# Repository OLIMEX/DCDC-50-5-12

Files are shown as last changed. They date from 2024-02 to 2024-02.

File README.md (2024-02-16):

# DCDC-50-5-12
Industrial grade -40+85C power supply module for OLinuXino. Suitrable also for 12 and 24V car battery systems.

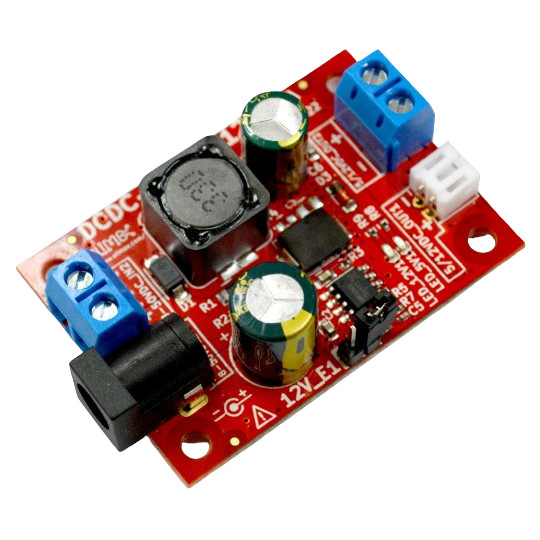
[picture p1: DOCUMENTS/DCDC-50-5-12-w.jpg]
DCDC-50-5-12-w


## Features

* Input voltage 8-50VDC
* Output voltage 5V/1.5A or 12V/1.5A
* Dimensions: 50x35x15mm

## Licenses

* Hardware is released under CERN Open Hardware Licence Version 2 - Strongly Reciprocal, all silkscreen credits to Olimex should remain;
* Software is released under GPL3 Licensee
* Documentation is released under CC BY-SA 4.0

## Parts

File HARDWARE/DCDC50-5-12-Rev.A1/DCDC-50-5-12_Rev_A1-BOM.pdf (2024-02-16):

# DCDC-50-5-12_Rev_A1-BOM 06/15/2022

Quantity | Designation | Package | Designator
2 | 1206 0.03 OHM 1% | R_1206 | R1,R2
1 | 0402 4.7 OHM 5% | R_0402 | R3
1 | 0402 1 K 5% | R_0402 | R9
1 | 0402 6.49 K 1% | R_0402 | R6
2 | 0402 10 K 1% | R_0402 | R5,R8
1 | 0402 56.2 K 1% | R_0402 | R7
1 | 33 uH 5.5A 60m 20% YSRH129-330M | HSMRH129_ 12.0x12.5x9.5(max) | L1
1 | 0402 12 PF 50V 5% C0G | C_0402 | C5
3 | 0603 100 NF 100V 10% X7R | C_0603 | C2,C4,C7
1 | 100 uF 63V 20% 10x13MM Low ESR RM5 | CPOL-RM5mm_ 10.0x16.0mm_PTH | C1
1 | 470 uF 16 V LOW ESR 20 % 8*12MM | CPOL-RM3.5mm_ 8.0x11.5mm_PTH | C6
1 | BZV55C6V2 | SOD80C-4148-KA | D3
1 | SMAJ58A | SMA | D1
1 | SS510 100V 5A 0.85V SMC | DO214AB(SMC) | D2
1 | LED 0603 RED 300 mCd | LED_0603 | LED_12V1
1 | LED 0603 GREEN 300 mCd | LED_0603 | LED_5V1
1 | TX4138(ESOIC-8) | ESOIC-8 | U1
1 | DW02R | DW02R | 5/12VDC_OUT1
2 | TB2-5MM | TB2-5mm | 8-50VDC_IN2, 5/12VDC_OUT2
1 | YDJ-1134 PWRJ-2mm (DCJ-R-20-LF) | PWRJ-2mm(YDJ-1134) | 8-50VDC_IN1
1 | HN1x2(Opened) | HN1x2_Jumper | 12V_E1
1 | NA(0603 22 OHM 5%) | R_0603_5MIL_DWS | R4
1 | NA(0805 220 PF C0G 100VDC) | C_0805_5MIL_DWS | C3

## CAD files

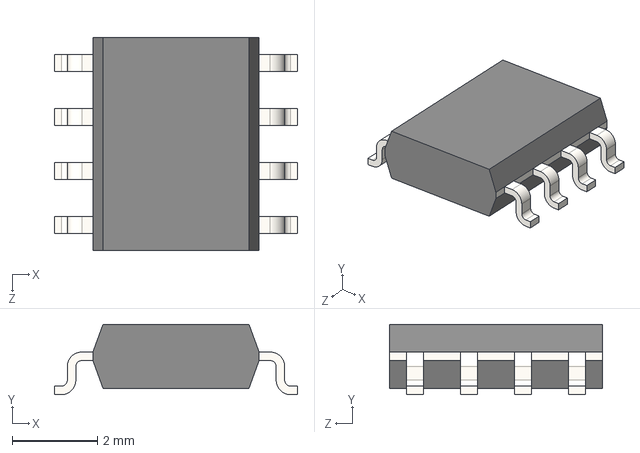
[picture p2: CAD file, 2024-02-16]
HARDWARE/DCDC50-5-12-Rev.A1/3d/SL08.step
5.70 x 1.65 x 5.00 mm

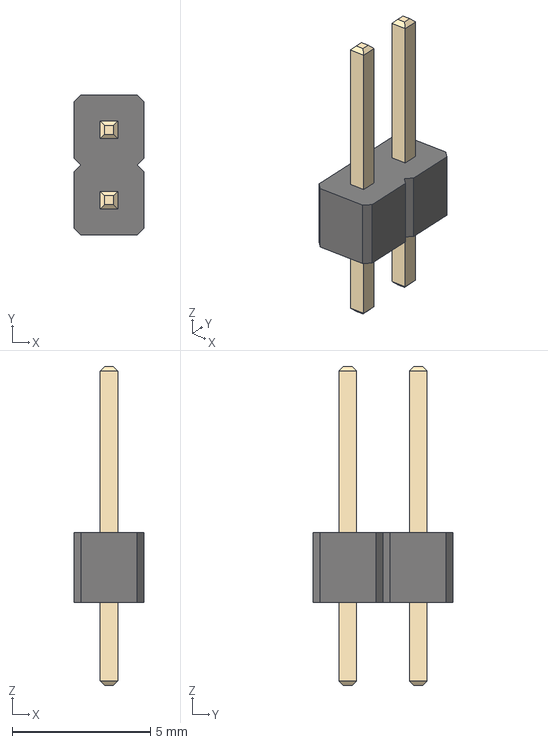
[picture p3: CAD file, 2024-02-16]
HARDWARE/DCDC50-5-12-Rev.A1/3d/HN1x2-PinHeader_1x02_P2.54mm_Vertical.step
2.54 x 5.08 x 11.5 mm

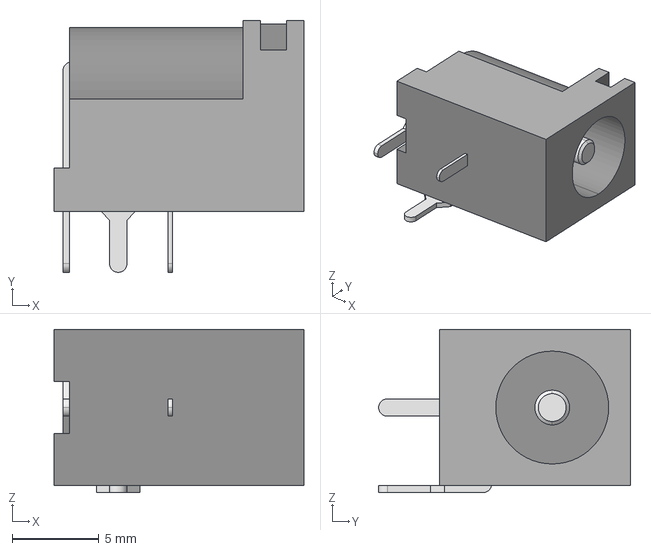
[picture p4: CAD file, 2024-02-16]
HARDWARE/DCDC50-5-12-Rev.A1/3d/pj-102ah.stp
14.4 x 14.5 x 9.40 mm

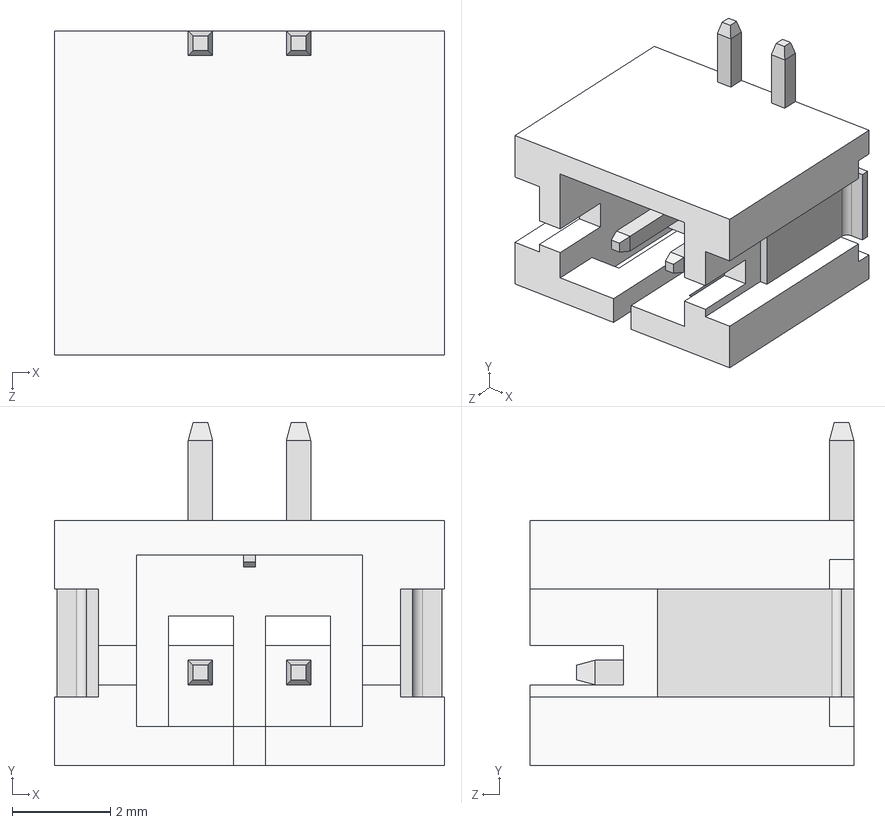
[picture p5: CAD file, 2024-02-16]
HARDWARE/DCDC50-5-12-Rev.A1/3d/JST_B2B-PH-SM4-TB(DW02R).step
7.95 x 7.00 x 6.60 mm

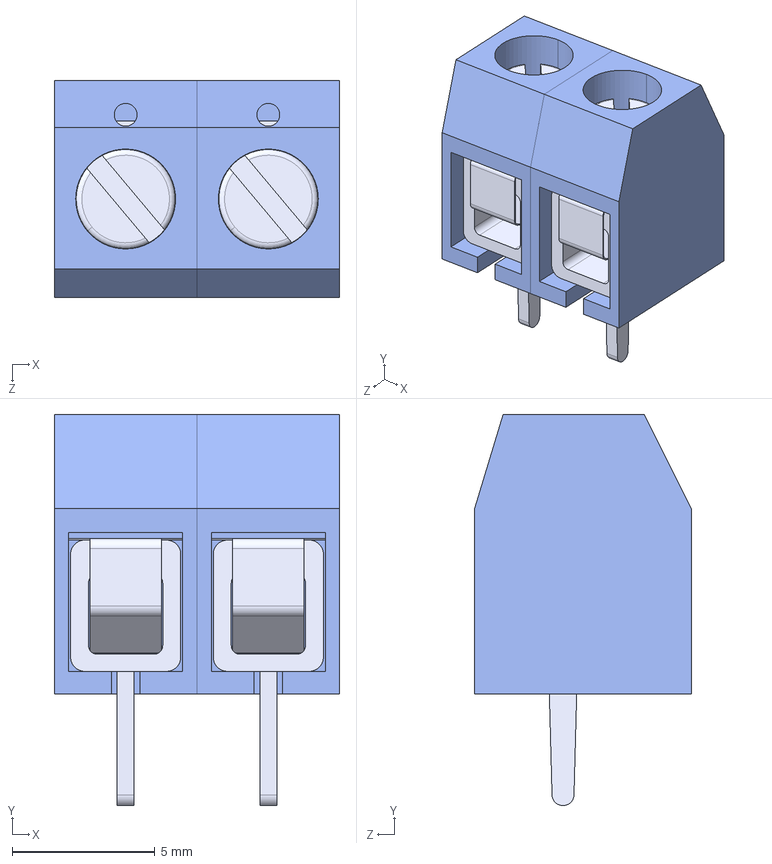
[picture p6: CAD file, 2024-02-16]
HARDWARE/DCDC50-5-12-Rev.A1/3d/TB2-5MM(DG306-5.0-2P).STEP
10.00 x 13.7 x 7.60 mm
Case___ _________ x 2
Leg___ _________ x 2
Spring___ _________ x 2
Cap___ _________ x 2

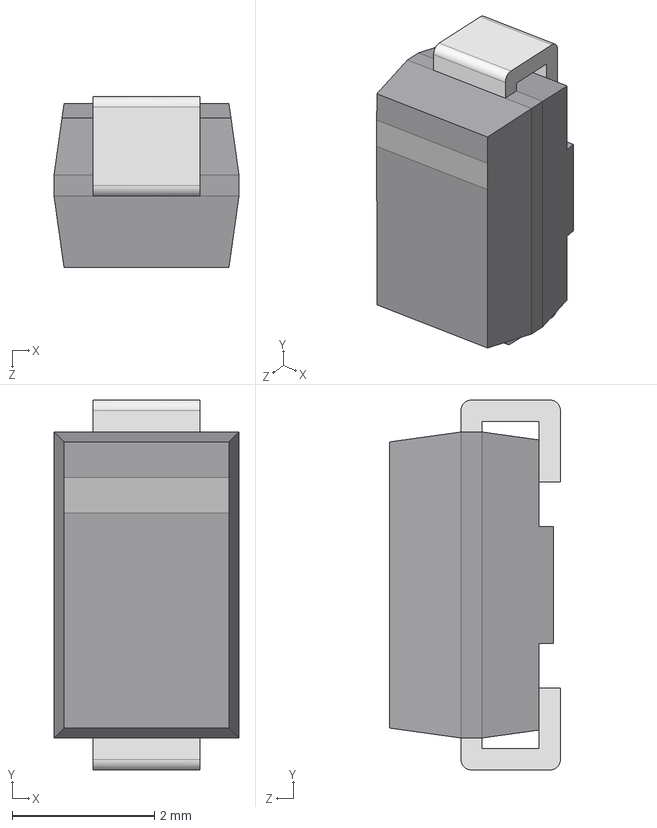
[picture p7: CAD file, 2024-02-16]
HARDWARE/DCDC50-5-12-Rev.A1/3d/DO-214AC_SMA.step
2.60 x 5.20 x 2.40 mm

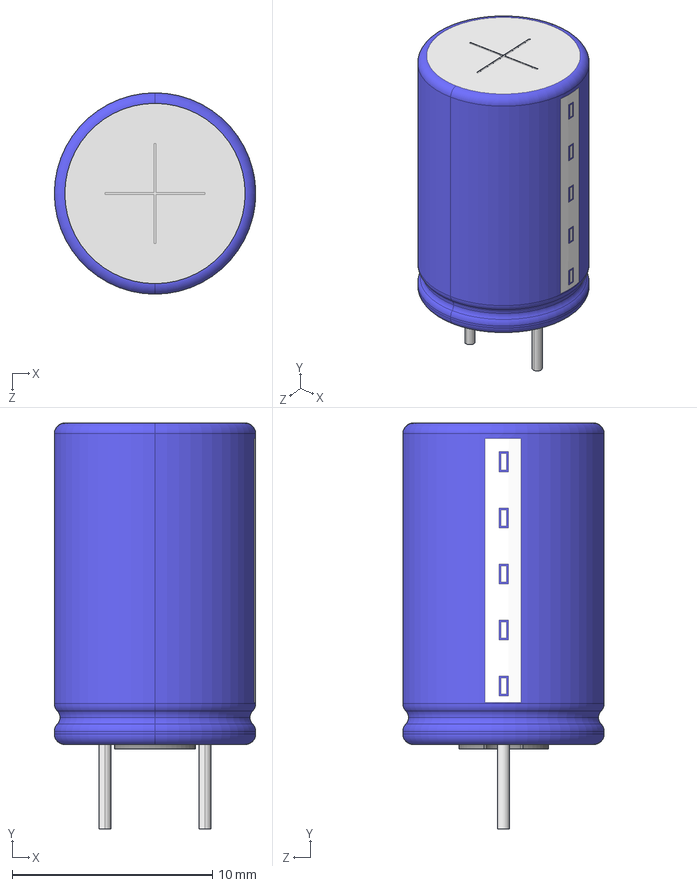
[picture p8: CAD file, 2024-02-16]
HARDWARE/DCDC50-5-12-Rev.A1/3d/Cap_PTH_10x16x5_0mm.step
10.1 x 20.3 x 10.1 mm

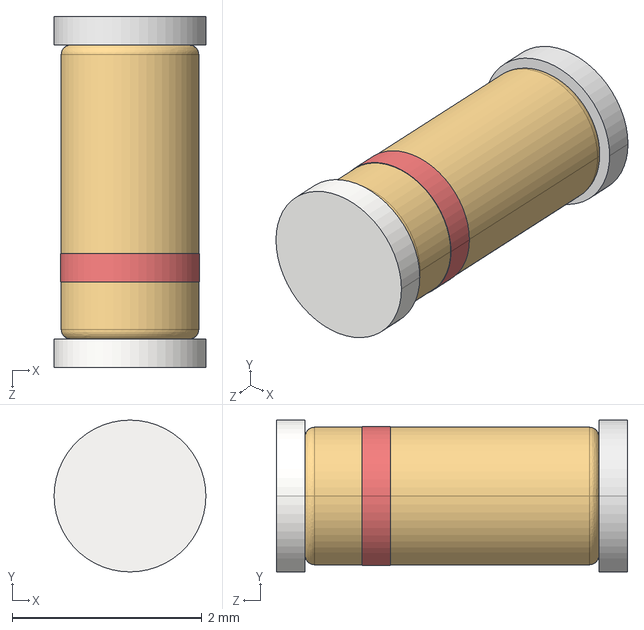
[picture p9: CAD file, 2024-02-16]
HARDWARE/DCDC50-5-12-Rev.A1/3d/melf-2_sod80c.step
1.60 x 1.60 x 3.70 mm

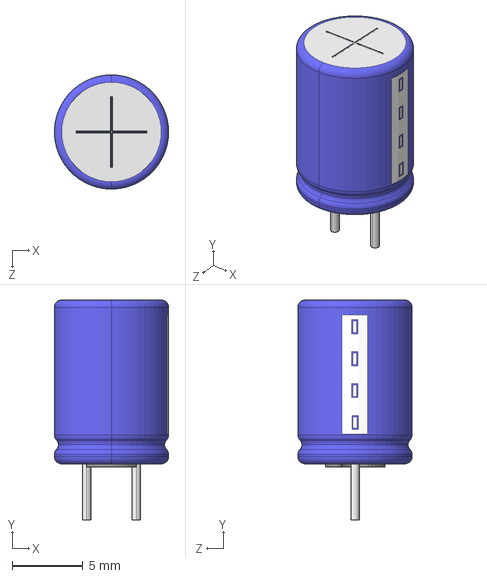
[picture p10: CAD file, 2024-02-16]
HARDWARE/DCDC50-5-12-Rev.A1/3d/Cap_8x11_5x3_5mm.step
8.05 x 15.5 x 8.05 mm

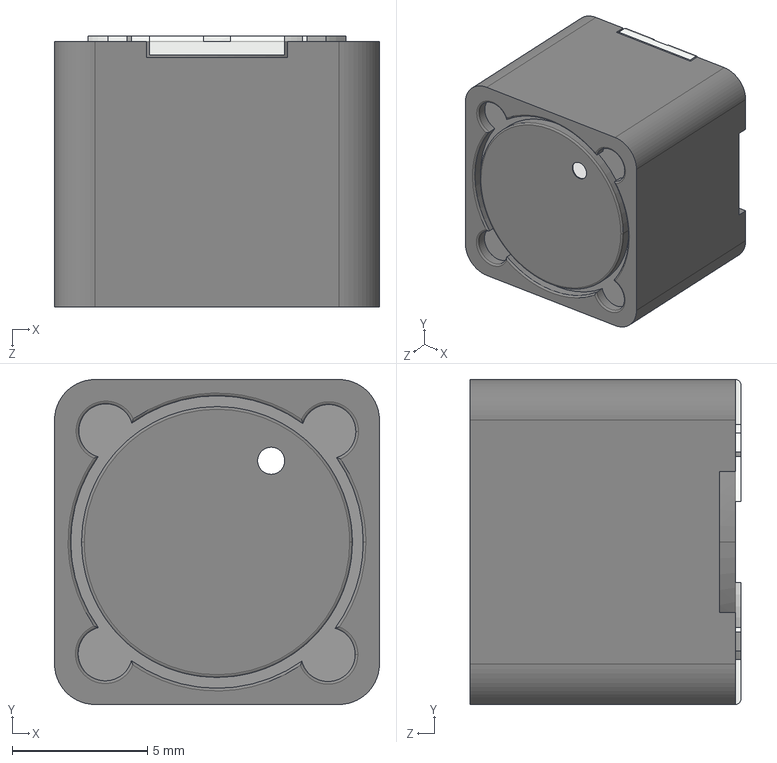
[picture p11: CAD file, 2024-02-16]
HARDWARE/DCDC50-5-12-Rev.A1/3d/L_HSMRH129---WE12x12x10.step
12.0 x 12.0 x 10.0 mm

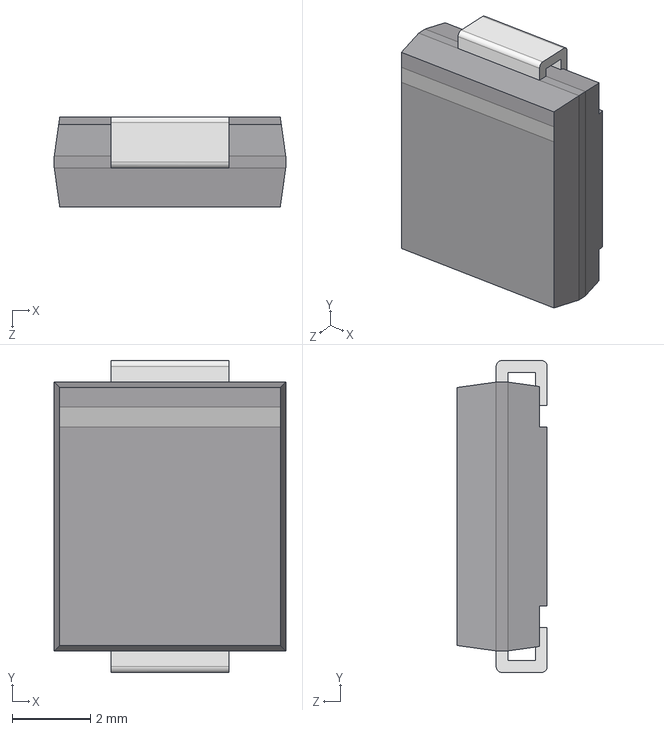
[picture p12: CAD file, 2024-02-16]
HARDWARE/DCDC50-5-12-Rev.A1/3d/DO-214AB_SMC.step
5.90 x 7.95 x 2.30 mm

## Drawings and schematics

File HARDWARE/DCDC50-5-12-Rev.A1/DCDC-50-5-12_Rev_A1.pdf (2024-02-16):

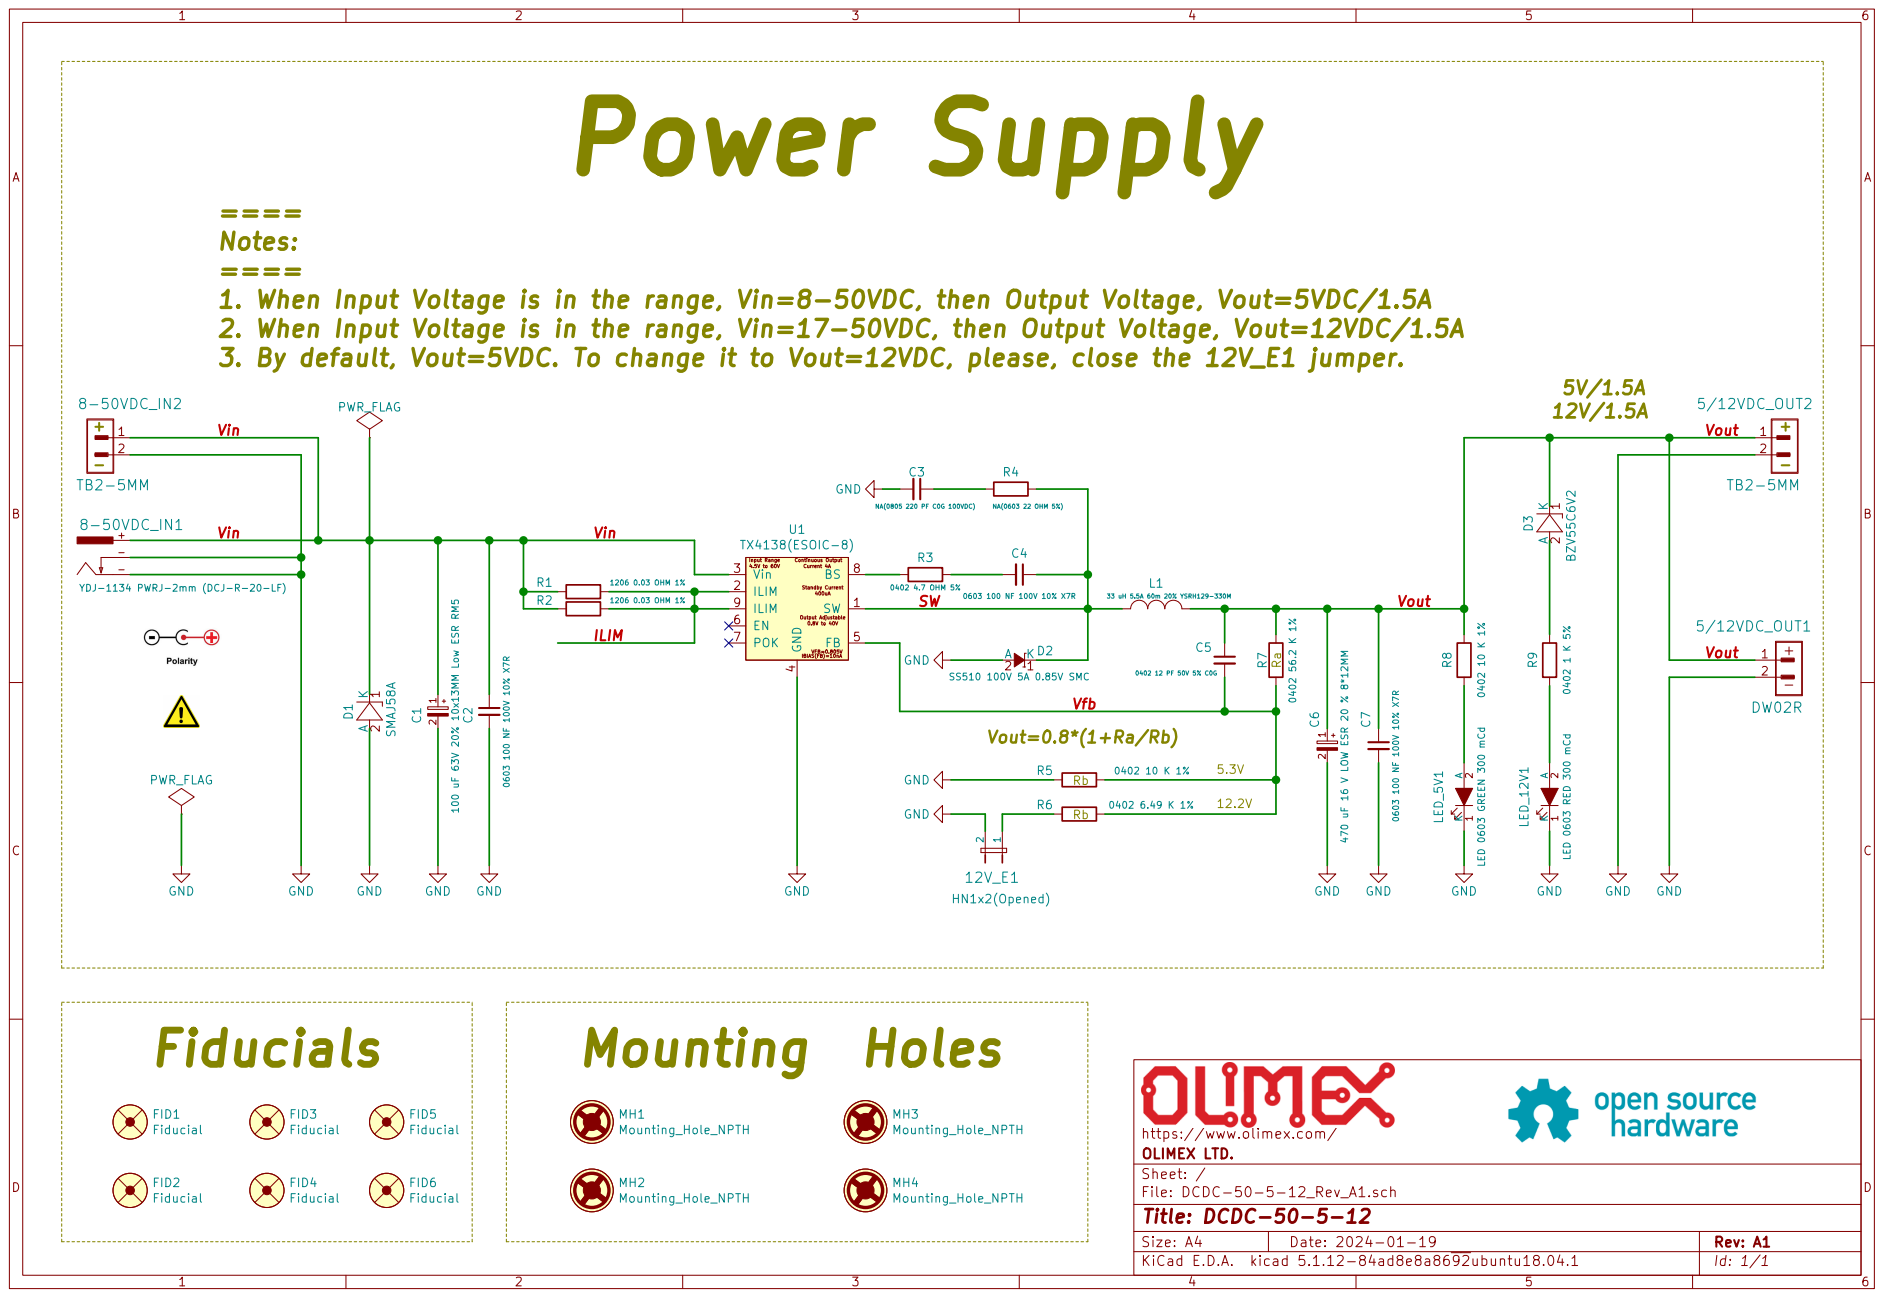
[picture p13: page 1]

1. When Input Voltage is in the range, Vin=8-50VDC, then Output Voltage, Vout=5VDC/1.5A
2. When Input Voltage is in the range, Vin=17-50VDC, then Output Voltage, Vout=12VDC/1.5A
3. By default, Vout=5VDC. To change it to Vout=12VDC, please, close the 12V_E1 jumper.

4 FB 5 EN 6 POK 7 BS 8

1 C1 2 100 uF 63V 20% 10x13MM Low ESR RM5 FID6 Fiducial FID4 Fiducial GND

2 LED_12V1 LED 0603 RED 300 mCd GND

File: DCDC-50-5-12_Rev_A1.sch Sheet: / OLIMEX LTD. https://www.olimex.com/

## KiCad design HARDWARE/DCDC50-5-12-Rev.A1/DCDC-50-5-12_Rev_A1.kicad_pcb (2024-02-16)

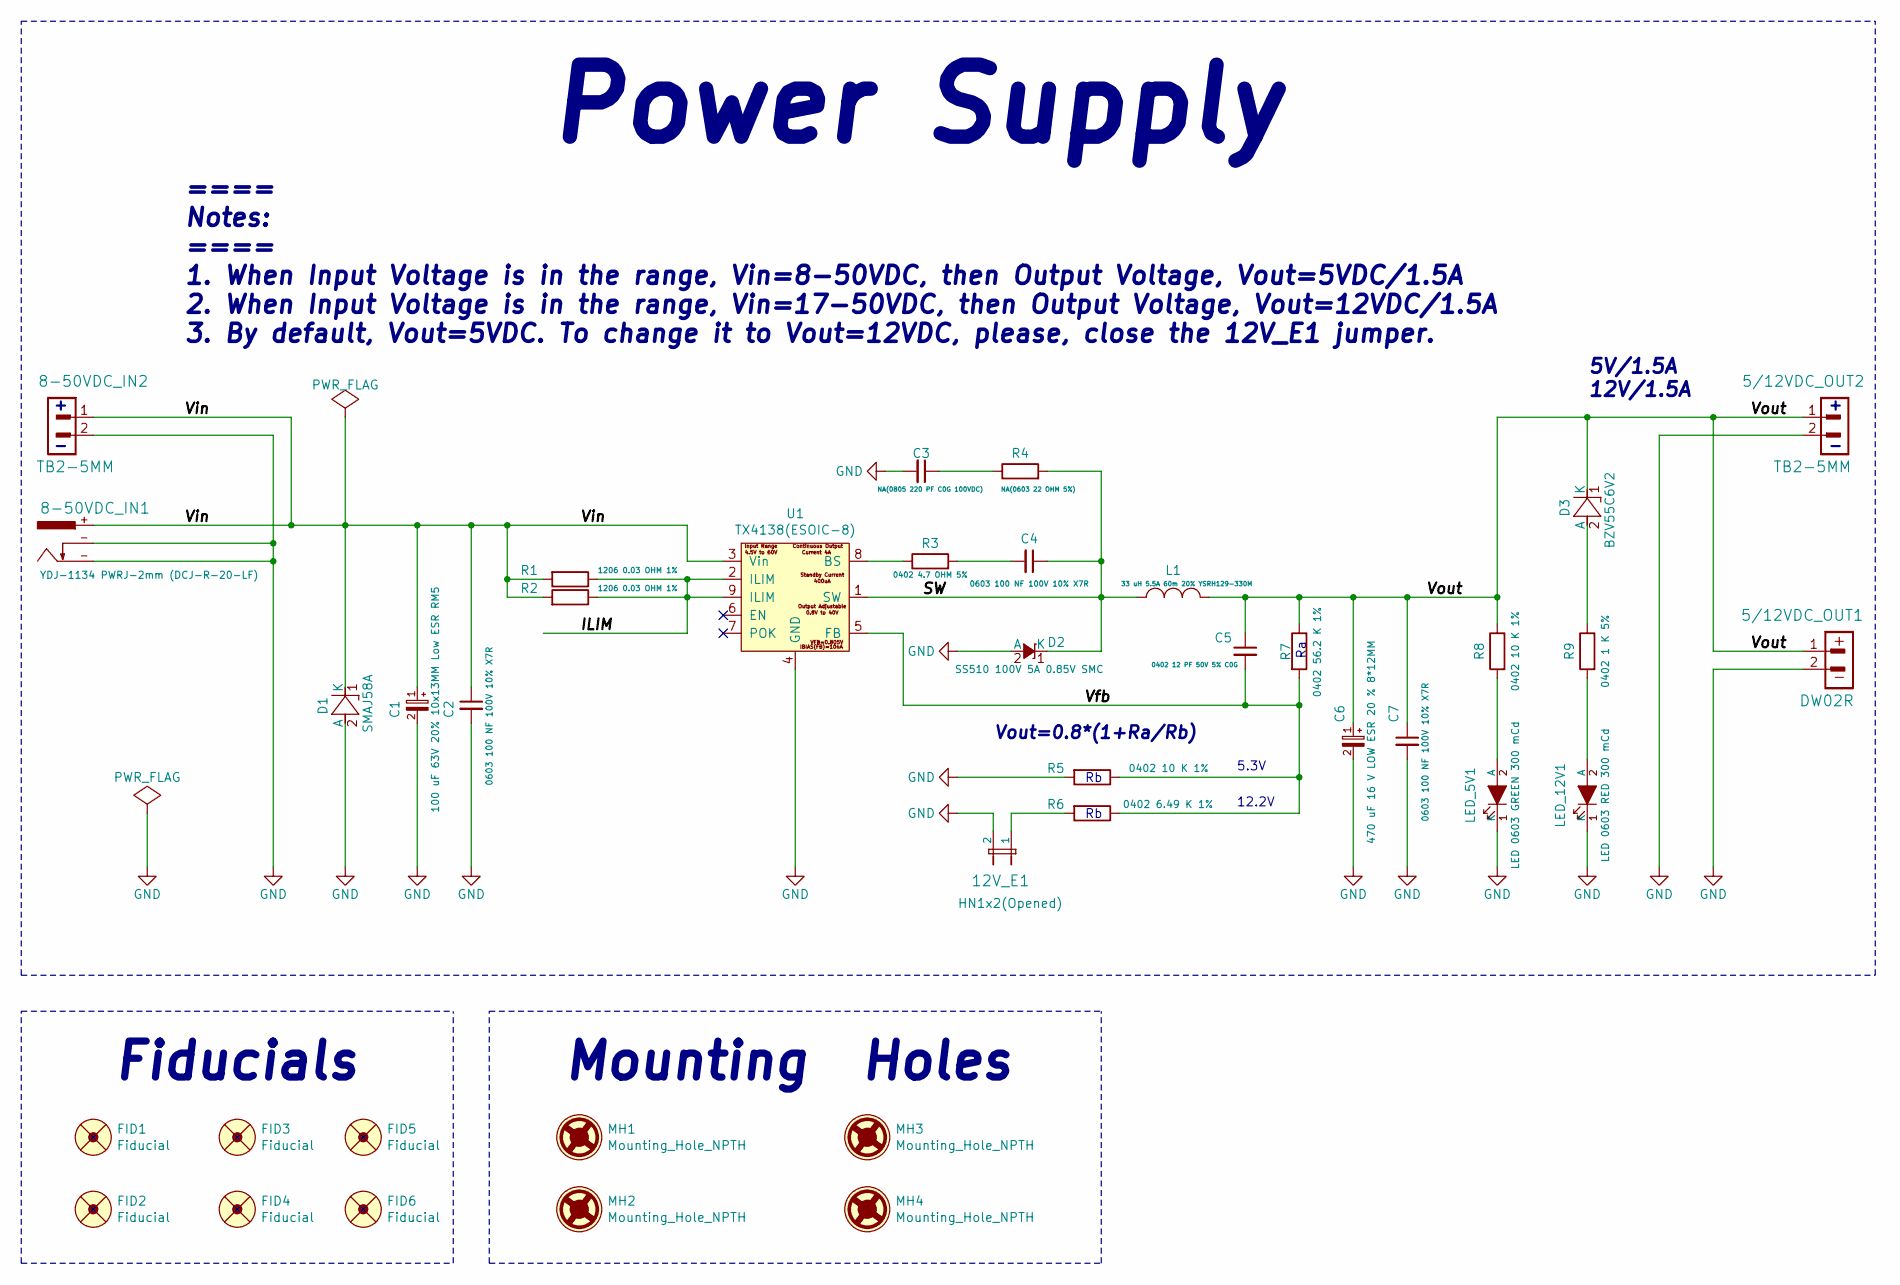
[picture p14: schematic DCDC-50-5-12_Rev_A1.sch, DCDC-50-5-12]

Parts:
5/12VDC_OUT1: DW02R; LIPO_BAT-CON2DW02R
5/12VDC_OUT2, 8-50VDC_IN2: TB2-5MM; TB2-5mm
8-50VDC_IN1: YDJ-1134 PWRJ-2mm (DCJ-R-20-LF); PWRJ-2mm(YDJ-1134)
12V_E1: HN1x2(Opened); HN1x2_Jumper
C1: 100 uF 63V 20% 10x13MM Low ESR RM5; CPOL-RM5mm_10.0x16.0mm_PTH
C2, C4, C7: 0603 100 NF 100V 10% X7R; C_0603_5MIL_DWS
C3: NA(0805 220 PF C0G 100VDC); C_0805_5MIL_DWS
C5: 0402 12 PF 50V 5% C0G; C_0402_5MIL_DWS
C6: 470 uF 16 V LOW ESR 20 % 8*12MM; CPOL-RM3.5mm_8.0x11.5mm_PTH
D1: SMAJ58A; SMA-KA
D2: SS510 100V 5A 0.85V SMC; DO214AB(SMC)_1(K)-2(A)
D3: BZV55C6V2; SOD80C-4148-KA
FID1, FID2, FID3, FID4, FID5, FID6: Fiducial; Fiducial1x3
L1: 33 uH 5.5A 60m 20% YSRH129-330M; HSMRH129_12.0x12.5x9.5(max)
LED_5V1: LED 0603 GREEN 300 mCd; LED_0603_KA
LED_12V1: LED 0603 RED 300 mCd; LED_0603_KA
MH1, MH2, MH3, MH4: Mounting_Hole_NPTH; Mounting_Hole_Drill-3.3mm_Clerance-7mm
R1, R2: 1206 0.03 OHM 1%; R_1206_5MIL_DWS
R3: 0402 4.7 OHM 5%; R_0402_5MIL_DWS
R4: NA(0603 22 OHM 5%); R_0603_5MIL_DWS
R5, R8: 0402 10 K 1%; R_0402_5MIL_DWS
R6: 0402 6.49 K 1%; R_0402_5MIL_DWS
R7: 0402 56.2 K 1%; R_0402_5MIL_DWS
R9: 0402 1 K 5%; R_0402_5MIL_DWS
U1: TX4138(ESOIC-8); ESOIC-8

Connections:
/ILIM: R1.1, R2.1, U1.2 (ILIM), U1.9 (ILIM)
/SW: C4.1, D2.1 (K), L1.1, R4.2, U1.1 (SW)
/Vfb: C5.2, R5.1, R6.1, R7.2, U1.5 (FB)
/Vin: 8-50VDC_IN1.+, 8-50VDC_IN2.1, C1.1 (+), C2.1, D1.1 (K), R1.2, R2.2, U1.3 (Vin)
/Vout: 5/12VDC_OUT1.1, 5/12VDC_OUT2.1, C5.1, C6.1 (+), C7.1, D3.1 (K), L1.2, R7.1, R8.1
GND: 5/12VDC_OUT1.2, 5/12VDC_OUT2.2, 8-50VDC_IN1.-, 8-50VDC_IN2.2, 12V_E1.2, C1.2 (-), C2.2, C3.2, C6.2 (-), C7.2, D1.2 (A), D2.2 (A), LED_5V1.1 (K), LED_12V1.1 (K), R5.2, U1.4 (GND)
unnamed: 12V_E1.1, R6.2
unnamed: C3.1, R4.1
unnamed: C4.2, R3.2
unnamed: D3.2 (A), R9.1
unnamed: LED_5V1.2 (A), R8.2
unnamed: LED_12V1.2 (A), R9.2
unnamed: R3.1, U1.8 (BS)

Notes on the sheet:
Fiducials
Vout=0.8*(1+Ra/Rb)
Mounting Holes
==== Notes: ==== 1. When Input Voltage is in the range, Vin=8-50VDC, then Output Voltage, Vout=5VDC/1.5A 2. When Input Voltage is in the range, Vin=17-50VDC, then Output Voltage, Vout=12VDC/1.5A 3. By default, Vout=5VDC. To change it to Vout=12VDC, please, close the 12V_E1 jumper.
Power Supply
5.3V
12.2V
5V/1.5A 12V/1.5A

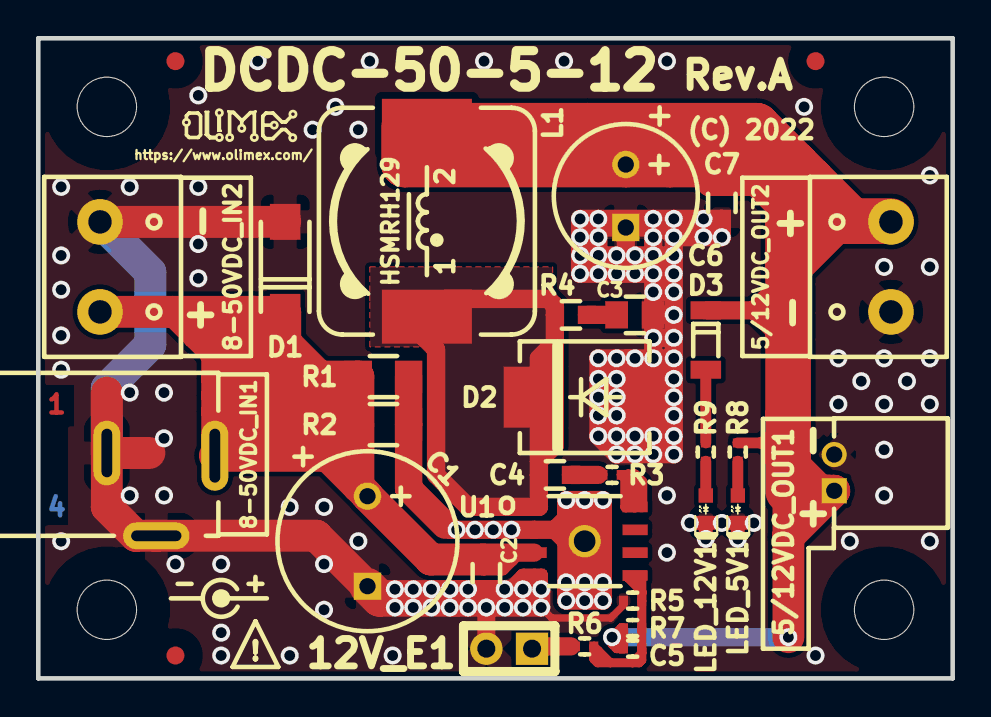
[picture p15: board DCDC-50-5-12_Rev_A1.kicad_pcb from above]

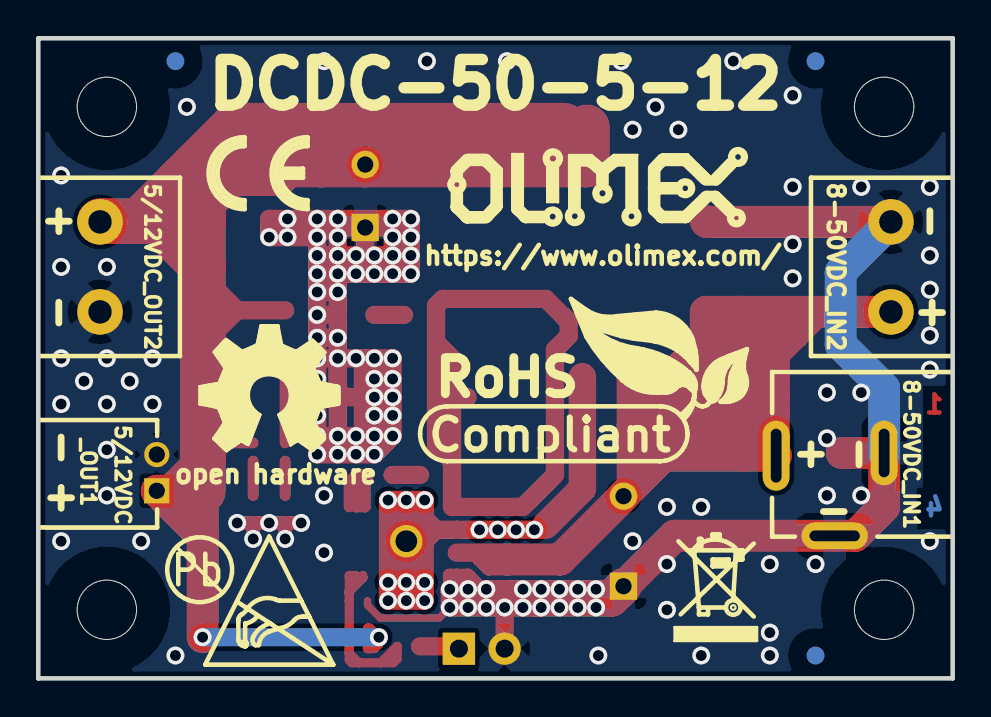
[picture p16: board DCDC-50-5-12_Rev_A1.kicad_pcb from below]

Board: 4 copper layers, 50.8 x 35.6 mm, 46 parts (10 on the bottom side), 13 nets.

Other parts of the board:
Logo_OLIMEX_SMALL_TB: Logo_OLIMEX_SMALL_TB
Logo_OSHW: LOGO_OPENHARDWARE_8x8
Logo_Olimex: OLIMEX_LOGO_TB
Sign_Antistatic: Val**; LOGO_ANTISTATIC_1
Sign_CE: CE_Sign
Sign_PB-Free: Sign_PB-Free
Sign_RecycleBin: LOGO_RECYCLEBIN_1
Sign_RoHS_1: Sign_RoHS_1

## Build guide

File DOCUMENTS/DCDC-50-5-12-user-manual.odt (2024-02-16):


DCDC-50-5-12

User Manual

Rev.1.0 February 2024 olimex.com

# What is DCDC-50-5-12

DCDC-50-5-12 is high effeciency DC to DC which delivers 5V/1.5A or 12V/1.5A from wide range of input voltage up to 50VDC.

It is suitable to deliver 5V for OlinuXino Linux computers from automotive 12V-24VDC power system.

When the output is 5VDC/1.5A the input power can be in range 8-50VDC.

When the output is 12VDC/1.5A the input power can be in 17-50VDC.

Default power output is 5VDC whrn 12V_E1 jumper is opened.

When 12V-E1 jumer is closed (cap on) the output voltage is 12VDC/1.5A.

The dimensions are: 50 x 35 x 15 mm.

The input can be supplied on two connectors:

1. Power barrel jack with 2.2 mm inner positive and outer 5.5 mm which is compatible with PWR-CABLE (https://www.olimex.com/Products/Components/Cables/PWR-CABLE/) and PWR-CABLE-RA (https://www.olimex.com/Products/Components/Cables/PWR-CABLE-RA/)

2. Screw terminal connector with 5 mm step for wires 0.2-2.0mm2

The output can is provided on two connectors:

1. Screw terminal connector with 5 mm step for wires 0.2-2.0mm2

2. 2.0 mm step JST cable connector which can be used with BATTERY-CABLE (https://www.olimex.com/Products/Components/Cables/BATTERY-CABLE/) (note colors are red for – and black for +)

## Order codes for DCDC-50-5-12:

DCDC-50-5-12 industrial grade -40+85C DCDC power supply

BATTERY-CABLE output power cable

PWR-CABLE input cable

PWR-CABLE-RA input cable

# HARDWARE

## DCDC-50-5-12 layout:

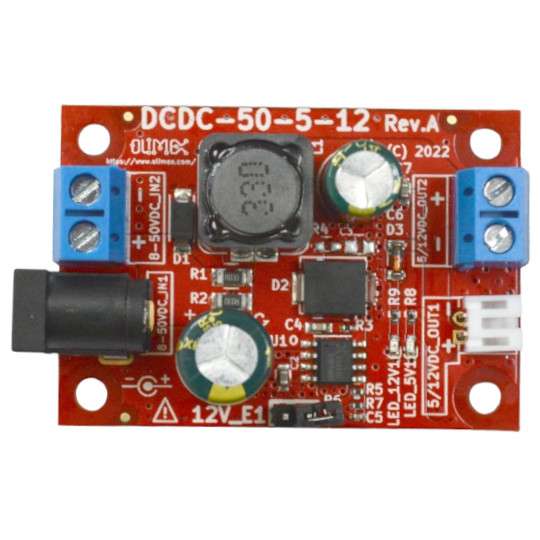
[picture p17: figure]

Output terminal block

Input terminal block

JST 2.0 mm connector

Input barrel jack 5.5mm

Output voltage jumper selection: open = 5V closed = 12V

## DCDC-50-5-12 schematics:

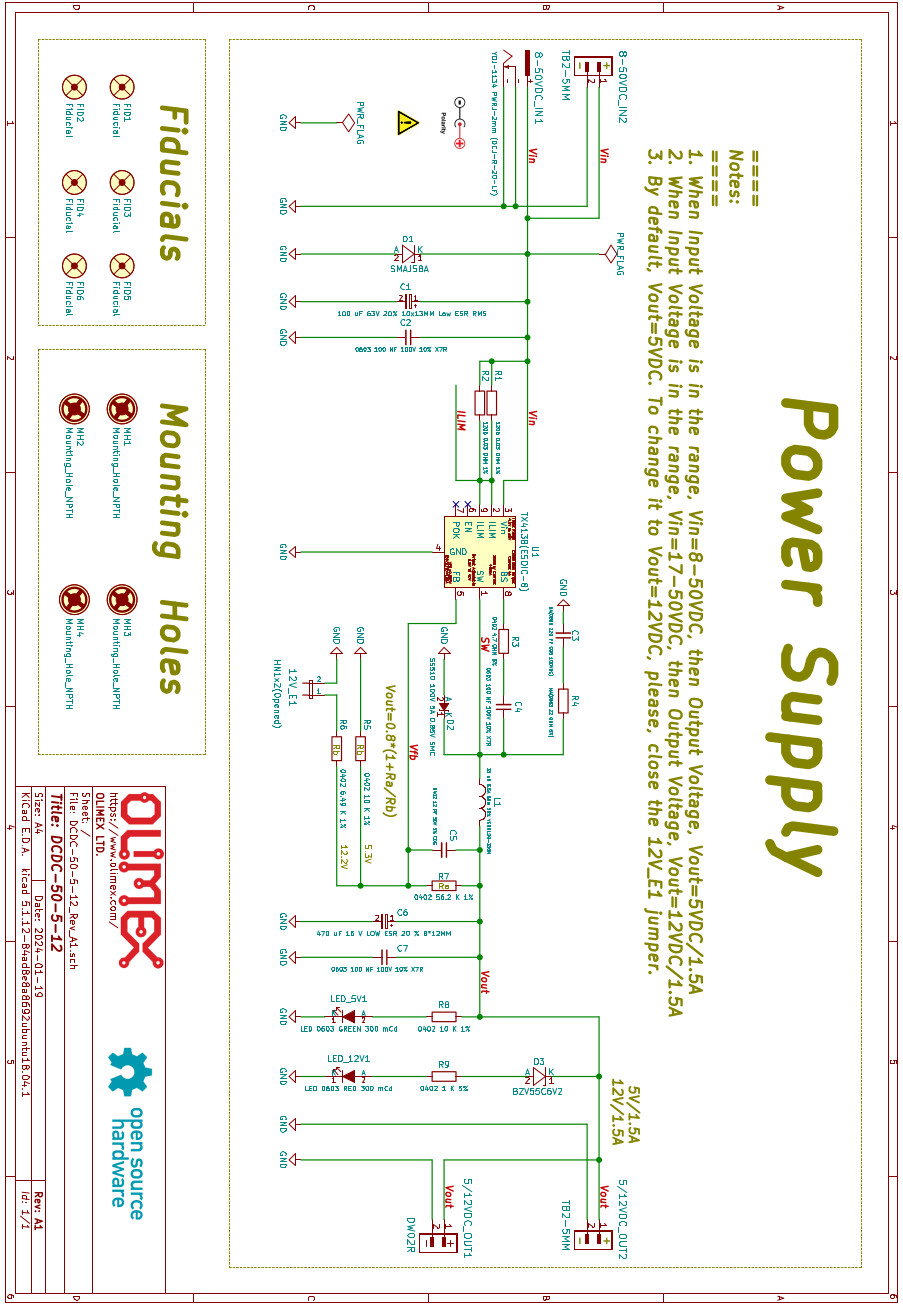
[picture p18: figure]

# Revision History

Revision 1.0 February 2024

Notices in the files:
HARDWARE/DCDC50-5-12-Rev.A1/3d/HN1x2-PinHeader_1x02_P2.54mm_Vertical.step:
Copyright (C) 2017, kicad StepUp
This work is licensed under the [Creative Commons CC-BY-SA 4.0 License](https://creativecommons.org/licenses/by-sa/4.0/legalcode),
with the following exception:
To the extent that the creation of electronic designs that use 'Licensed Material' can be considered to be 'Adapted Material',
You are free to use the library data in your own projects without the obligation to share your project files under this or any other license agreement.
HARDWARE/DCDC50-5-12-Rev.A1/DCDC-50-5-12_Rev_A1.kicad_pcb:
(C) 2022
